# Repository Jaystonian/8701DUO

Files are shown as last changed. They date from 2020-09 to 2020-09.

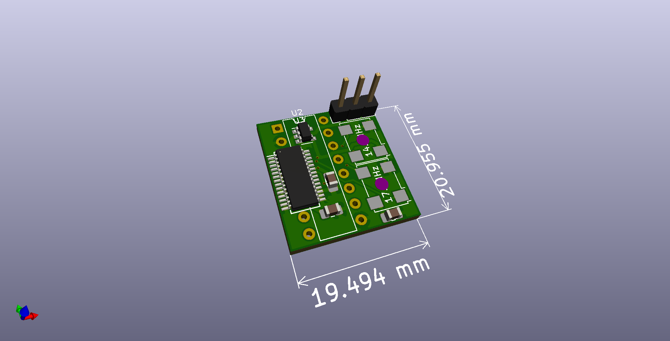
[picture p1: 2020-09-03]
img/8701Duo-Top.png

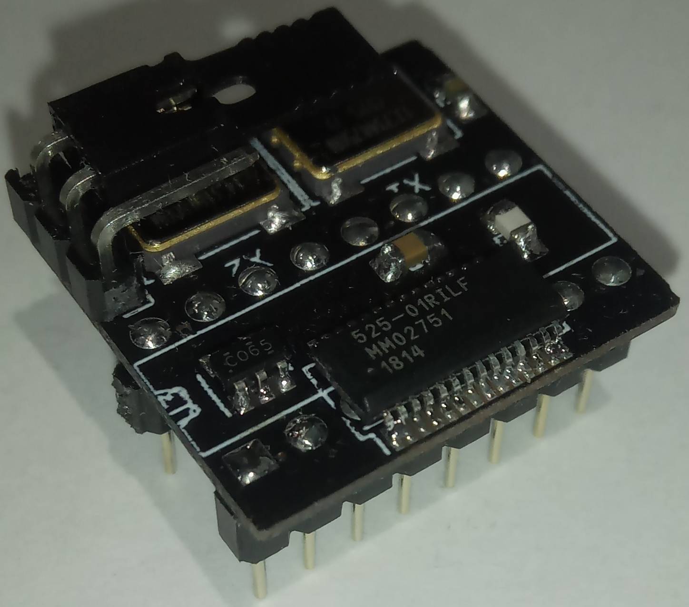
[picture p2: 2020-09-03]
img/IMG_20200902_212604_7.jpg

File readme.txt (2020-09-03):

Tested early August 2020.  Works great.  Needed to reverse the clock chips, corrected all files.  
NTSC standard clock should be next to the 3-SIP pin header.

PARTS
=====================
IDT 525-01RILFT (or 525-02R etc)
SN74LVC1G06DBVR (or 1g04, or 1g14, hct, ahct etc)
LFSPXO020648 (17.734MHz)
LFSPXO021772 (14.318MHz)          
2x 10nF 0805/2012 (for ics525)
2x 100nF 0805/2012 (for clocks & gate)
1x 20pF 0805/2012 
1x 8k2 0805/2012 (as pullup resistor)

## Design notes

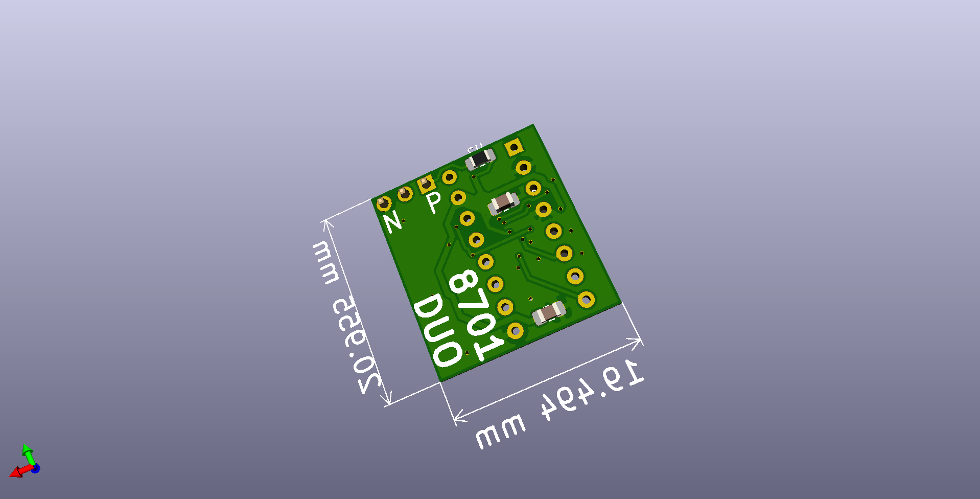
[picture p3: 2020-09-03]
img/8701Duo-Bottom.png

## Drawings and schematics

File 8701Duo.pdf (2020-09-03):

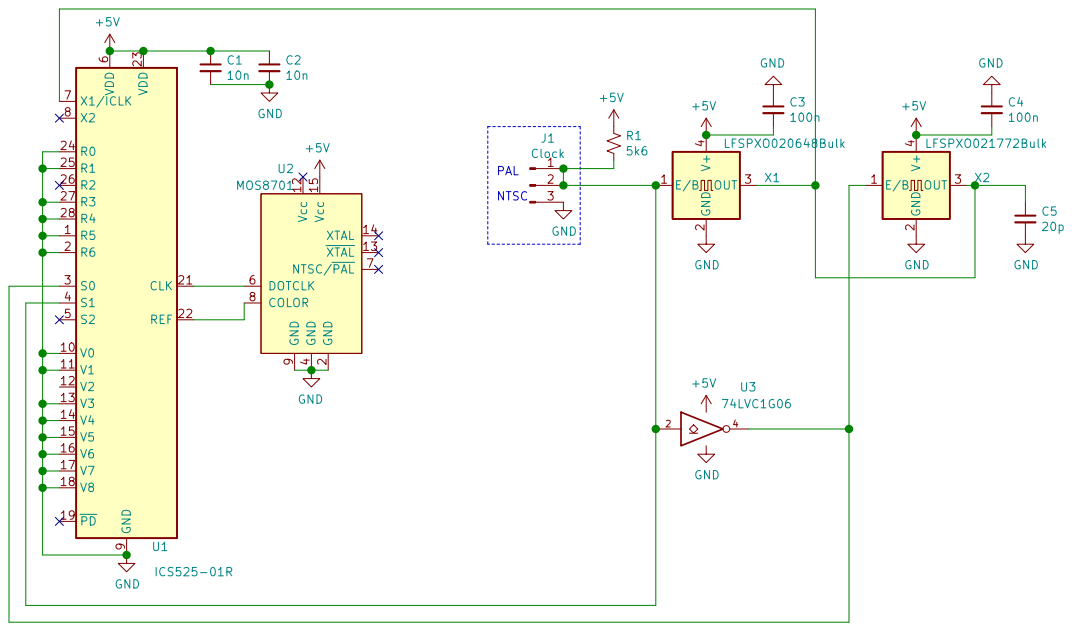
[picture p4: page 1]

4 DOTCLK 6 NTSC/PAL 7 COLOR 8 GND

File: 8701Duo.sch Sheet: / Jaystonian

Id: 1/1 Title: MOS8701 replacement with dual oscillators

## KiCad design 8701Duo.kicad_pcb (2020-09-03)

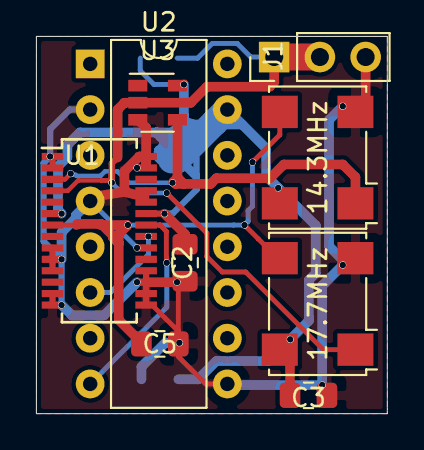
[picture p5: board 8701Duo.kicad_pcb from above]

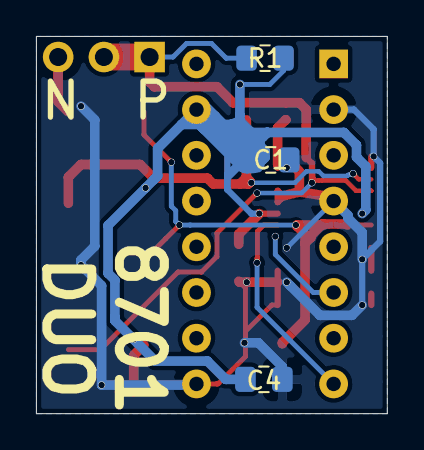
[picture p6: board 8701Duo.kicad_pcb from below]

Board: 2 copper layers, 19.5 x 21.0 mm, 12 parts (3 on the bottom side), 7 nets.

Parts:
14.3MHz: LFSPXO021772Bulk; Oscillator_SMD_IQD_IQXO70-4Pin_7.5x5.0mm
17.7MHz: LFSPXO020648Bulk; Oscillator_SMD_IQD_IQXO70-4Pin_7.5x5.0mm
C1, C2: 10n; C_0805_2012Metric_Pad1.15x1.40mm_HandSolder
C3, C4: 100n; C_0805_2012Metric_Pad1.15x1.40mm_HandSolder
C5: 15p-45p; C_0805_2012Metric_Pad1.15x1.40mm_HandSolder
J1: Clock; PinHeader_1x03_P2.54mm_Vertical
R1: 5k6; R_0805_2012Metric_Pad1.15x1.40mm_HandSolder
U1: ICS525-01R; SSOP-28_3.9x9.9mm_P0.635mm
U2: MOS8701; DIP-16_W7.62mm
U3: 74LVC1G06; SOT-23-5

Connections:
+5V: 14.3MHz.4, 17.7MHz.4, C1.1, C2.1, C3.2, C4.2, R1.1, U1.6, U1.23, U2.15, U3.5
GND: 14.3MHz.2, 17.7MHz.2, C1.2, C2.2, C3.1, C4.1, C5.2, J1.3, U1.1, U1.2, U1.9, U1.10, U1.11, U1.13, U1.14, U1.15, U1.16, U1.17, U1.18, U1.20, U1.24, U1.25, U1.27, U1.28, U2.2, U2.4, U2.9, U3.3
unnamed: 14.3MHz.3, 17.7MHz.3, C5.1, U1.7
unnamed: 14.3MHz.1, J1.1, J1.2, R1.2, U1.4, U3.2
unnamed: 17.7MHz.1, U1.3, U3.4
unnamed: U1.21, U2.6
unnamed: U1.22, U2.8

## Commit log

2020-06-22 Untested. Will update to confirm working.
    [8701Duo-B_Cu.gbr, 8701Duo-B_Mask.gbr, 8701Duo-B_SilkS.gbr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]
2020-08-23 works great
    [8701Duo.sch]
